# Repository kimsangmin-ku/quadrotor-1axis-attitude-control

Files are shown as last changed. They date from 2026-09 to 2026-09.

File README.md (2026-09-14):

# quadrotor-1axis-attitude-control

F450 쿼드로터의 한 축만 움직이게 지그에 고정하고, 직접 만든 제어기로 수평을 잡아보는 프로젝트.

## 왜 하죠?

이번 2학기에 듣는 [항공우주종합설계와 센서 및 계측공학] 이 두 과목에서 배우는 지식을 결합하여 실제 제어기를 만들어보고 비교적 간단한 구동 실험을 통해 실전 감각을 확보하려고

## 쓰는 것들

- 보드: STM32 Nucleo-F446RE
- IMU: MPU-6050
- 모터/ESC: 2212 1000KV × 2 (예비 1), 30A ESC × 2, 1045 프로펠러
- 지그: 알루미늄 프로파일 + 3D프린팅 (CATIA로 설계)
- 분석: Python

## 진행

- [x] 부품 발주
- [ ] 보드 세팅, 시리얼 출력
- [ ] 지그 설계 (CATIA)
- [ ] IMU 읽기
- [ ] 각도 추정 (상보필터)
- [ ] 지그 조립, 모터 구동
- [ ] PID 폐루프
- [ ] 게인 튜닝 + 데이터 정리
- [ ] 시뮬레이션이랑 비교 (시간 되면)

계획서: [docs/project_plan.md](docs/project_plan.md)
진행 기록: [docs/progress_log.md](docs/progress_log.md)

## 결과

(아직 없음)

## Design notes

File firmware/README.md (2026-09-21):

# firmware

개인 소유 **STM32 Nucleo-F446RE** 용 PlatformIO 프로젝트.
항공우주종합설계 수업의 LPC1768 프로젝트와는 폴더·플랫폼(`ststm32` vs `nxplpc`)·코드 모두 별개이며,
수업 코드를 복사하지 않고 처음부터 작성한다.

## 빌드·업로드

1. VS Code에서 **이 저장소 루트가 아니라 `firmware` 폴더**를 연다 (File → Open Folder).
2. Nucleo를 ST-LINK 쪽 USB(보드 위쪽)로 PC에 연결한다. 수업 보드는 동시에 꽂지 않는다.
3. PlatformIO 상태바의 → (Upload) 클릭. 첫 빌드는 mbed 라이브러리를 받느라 수 분 걸린다.
4. 플러그 아이콘 (Serial Monitor) 클릭. 115200 bps.

성공 기준: 초록 LED(LD2)가 0.5초마다 깜빡이고, 모니터에 `tick N  t=... ms` 가 흐른다.

## 구조 (예정)

```
firmware/
├── platformio.ini
├── src/
│   ├── main.cpp        제어 루프 (100 Hz)          ← 현재: LED + 시리얼 생존 확인
│   ├── imu.cpp/.h      MPU-6050 I2C 읽기
│   ├── filter.cpp/.h   상보필터
│   ├── pid.cpp/.h      PID 제어기
│   └── logger.cpp/.h   UART CSV 로깅
└── docs/wiring.md      배선도
```

## 진행

- [x] platformio.ini + main.cpp 생성 (2026-09-21)
- [x] 보드 업로드·시리얼 출력 확인 (2026-09-21, mbed 드라이브 복사 방식)
- [x] MPU-6050 읽기 (2026-09-21, 클론 칩 WHO_AM_I=0x72)
- [ ] 상보필터 roll 각도 추정

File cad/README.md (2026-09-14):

# cad

1축 테스트 지그 설계 파일.

- `*.CATPart`, `*.CATProduct`, `*.CATDrawing` : CATIA 원본
- `step/` : STEP 내보내기 (타 프로그램에서 열람용)
- `drawings/` : 2D 도면 PDF
- `bom.md` : 부품표
- `design_notes.md` : 재료·치수 선정 근거, 지그 강성 손계산

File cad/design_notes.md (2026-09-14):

# 프레임 재료
3개 정도 후보에 있음

1. 알루미늄 프로파일
2. 목재
3. 3d 프린팅

# 각각 특징 그리고 현실적으로 되는지...
1. 알루미늄 프로파일 : 강성 좋음, 수정 가능(**)
2. 목재 : 저렴함, 도구 필요, 수정 어려움;
3. 3d 프린팅 : 내가 의도한대로 만들 수 있음 but 큰 부품 만들면 휠 가능성 배제 못함. 

## 결정
- (9/14) 알루미늄으로 가자.
 치수 수정이 가능하다는 점을 포기할 수가 없음.

## 쓰고나서 후기 남겨볼게요
---

## 2. 회전축 방식

(볼베어링 / 부싱 / 볼트 구멍 — 위와 같은 형식으로)

## 3. 보드

(Nucleo / Arduino / ESP32)

## 4. 전원

(파워서플라이 / LiPo)

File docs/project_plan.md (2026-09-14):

# 개인프로젝트 I 계획서
## 1축 테스트벤치 기반 쿼드로터 자세 안정화 제어기 개발·검증

작성일: 2026-09-14 | 작성자: 김상민 | 기간: 2026-09-15 ~ 2026-12-04 (12주)

---

## 1. 프로젝트 한 줄 정의

F450 쿼드로터의 한 축(roll)만 회전하도록 고정하는 시소형 테스트 지그를 직접 설계·제작하고, 개인 소유 MCU로 IMU 기반 자세 추정과 PID 제어기를 구현해 수평 유지 성능을 정량적으로 시험·튜닝·검증한다.

## 2. 왜 이 주제인가 (지원 직무와의 연결)

| 결과물 층 | 산출물 | 앞세울 회사·직무 |
|---|---|---|
| 1층 설계 | CATIA 3D 모델, 2D 도면, BOM, 설계 근거서, 지그 강성 손계산 | KAI·한화에어로·LIG 기계/구조 설계, 현대차 차량시스템 설계 |
| 2층 제어 | 자세 추정 코드, PID 제어 코드, 게인별 스텝응답 표·그래프 | 현대차 차량제어 SW, LG전자 로봇, 방산 유도제어·항공전자 |
| 3층 검증 | 1축 동역학 모델(Python/MATLAB), 시뮬레이션 vs 실측 비교 | 현대차 SDV, 방산 디지털 엔지니어링·시험평가 |

프로젝트는 하나, 자소서 서사는 세 개. 회사마다 바뀌는 건 프로젝트가 아니라 강조하는 층이다.

## 3. 전제와 제약

- 보유 부품 없음 (Mbed LPC1768은 수업용 대여 보드이므로 개인 프로젝트에는 사용하지 않음)
- 예산 30~80만 원
- 작업 시간은 평일만, 주당 약 6~8시간 가정
- 실제 비행 없음 (장소·자격증 문제) → 벤치 시험으로 전 과정 대체
- 진동해석 제외, 3D프린팅은 온라인 출력 대행
- 수업(항공전자모빌리티종합설계)과의 구분: 수업은 "시중 드론 보드 교체 후 동작", 개인 프로젝트는 "제어기 한 개를 실물에서 정량 시험·튜닝·검증"

## 4. MCU 선정 (핵심 결정)

**추천: STM32 Nucleo-F446RE (또는 F401RE)** — 약 2~3만 원

- 수업에서 쓰는 Mbed 생태계와 동일해 수업에서 배운 코드·PlatformIO 환경이 그대로 이식됨 (학습 비용 최소)
- 개인 소유이므로 프로젝트 소유권이 명확하고 졸업 후에도 보유
- STM32는 현대차·LG·방산 임베디드 직무에서 실제로 가장 많이 쓰는 계열이라 이력서에 쓸 때 가장 유리
- 대안: Arduino Nano (1만 원, 가장 쉬움, 어필도는 낮음) / ESP32 (1만 원, 무선 로깅 편리, 항공·차량 쪽 어필은 STM32보다 약함)

## 5. 부품 목록 및 예산 (예상)

| 구분 | 품목 | 수량 | 예상 금액 |
|---|---|---|---|
| MCU | Nucleo-F446RE | 1 | 30,000 |
| 센서 | MPU-6050 (또는 MPU-9250) IMU 모듈 | 1 | 5,000 |
| 구동 | 2212 920KV 브러시리스 모터 | 2 (+예비 1) | 40,000 |
| 구동 | 30A ESC (BLHeli) | 2 | 25,000 |
| 구동 | 8045 프로펠러 세트 (정·역회전) | 2세트 | 10,000 |
| 기체 | F450 프레임 (팔 2개 + 센터 플레이트 사용) | 1 | 25,000 |
| 전원 | 12V 10A 이상 DC 파워서플라이 (LiPo 대신, 벤치용이라 안전) | 1 | 30,000 |
| 지그 | 2020 알루미늄 프로파일 + 브라켓 + 볼트 | 1식 | 30,000 |
| 지그 | 볼베어링 (608ZZ 등), 8mm 샤프트 | 1식 | 10,000 |
| 지그 | 3D프린팅 출력 대행 (베어링 하우징, 기체 마운트, 프로펠러 가드) | 1식 | 40,000 |
| 기타 | 점퍼선, 브레드보드, XT60/바나나 커넥터, 케이블타이, 절연테이프 | 1식 | 15,000 |
| 안전 | 보호안경, 비상정지용 토글 스위치 | 1식 | 10,000 |
| **합계** | | | **약 270,000원** (예비비 포함 35만 원 이내) |

발주 우선순위: MCU·IMU → 모터·ESC·전원 → 프레임·지그 재료 → 출력 대행(설계 완료 후).

## 6. 주차별 일정 (12주)

| 주차 | 기간 | 목표 | 완료 기준 |
|---|---|---|---|
| 1 | 9/15~9/19 | 요구사항 정의, 1축 개념설계 스케치, 1차 부품 발주 (MCU·IMU·모터·ESC·전원) | 요구사항 문서 1장, 발주 완료 |
| 2 | 9/22~9/26 | PlatformIO 환경 세팅, Nucleo LED·시리얼 동작, 1축 동역학 손계산 (추력↔토크↔각가속도) | "Hello" 시리얼 출력, 계산 노트 1장 |
| 3 | 9/29~10/3 | CATIA 지그 설계 (프로파일 프레임, 베어링 하우징, 기체 마운트, 프로펠러 가드) | 3D 모델 완성 |
| 4 | 10/6~10/10 | 도면·BOM 작성, 지그 강성 손계산(외팔보 처짐), 출력 대행·프로파일 발주 / IMU I2C 읽기 | 도면 세트, IMU 원시값 시리얼 출력 |
| 5 | 10/13~10/17 | 상보필터로 roll 각도 추정, 정지·기울임 상태에서 각도 검증 (중간고사 주간 — 부하 낮게) | 각도 ±2° 이내 추정 |
| 6 | 10/20~10/24 | 지그 조립, ESC 캘리브레이션, 모터 PWM 개루프 구동, 비상정지 확인 | 두 모터 독립 구동, 지그에서 수동 균형 확인 |
| 7 | 10/27~10/31 | P 제어만으로 폐루프 첫 동작, 시리얼 데이터 로깅 파이프라인 (CSV) | 제어 루프 100Hz 이상, 로그 파일 생성 |
| 8 | 11/3~11/7 | PID 완성, 게인 튜닝 1차 (Ziegler-Nichols 또는 수동) | 스텝 입력에서 수평 복귀 |
| 9 | 11/10~11/14 | 게인별 스텝응답 비교 실험 (최소 5세트), 오버슈트·정착시간·정상상태오차 표·그래프 | 비교표 + 그래프 완성 ← **최소 완료선** |
| 10 | 11/17~11/21 | (3층) Python으로 1축 모델 구성, 시뮬레이션 스텝응답 | 시뮬레이션 그래프 |
| 11 | 11/24~11/28 | (3층) 시뮬레이션 vs 실측 겹쳐 그리기, 오차 원인 분석 1문단 / 포트폴리오 초안 | 비교 그래프, 초안 |
| 12 | 12/1~12/4 | 최종 문서화, 동작 영상 촬영, 회사별 서사 3종 정리 | 포트폴리오 PDF, 영상 1분 |

**컷 규칙**: 11/14까지 9주차(스텝응답 비교표)가 안 끝나면 10~11주차(3층)를 버리고 2층 완성도에 집중한다. 완성된 두 층이 미완성 세 층보다 강하다.

## 7. 최종 산출물

1. 설계 패키지: CATIA 모델, 도면, BOM, 설계 근거서(재료·치수 선정 이유), 강성 손계산
2. 코드: GitHub 저장소 (README에 배선도, 빌드 방법, 제어 구조도)
3. 실험 데이터: 게인별 스텝응답 CSV + 그래프 + 비교표
4. (선택) 모델 검증: 시뮬레이션 vs 실측 비교 그래프 + 분석
5. 포트폴리오 문서 (PDF 6~10쪽) + 동작 영상 1분
6. 회사별 자소서용 서사 3종 (설계형 / 제어형 / 설계-제어 통합형)

## 8. 리스크와 대응

| 리스크 | 대응 |
|---|---|
| 부품 배송 지연 (해외 직구 시 2~3주) | 국내 재고 우선 구매, 1주차에 즉시 발주 |
| 출력 대행 치수 오차로 베어링 안 맞음 | 하우징 공차 +0.2mm, 조립 전 시험 출력 1개 |
| IMU 진동 노이즈로 각도 튐 | 센서를 폼테이프로 마운트, 필터 계수 조정, 로우패스 추가 |
| 모터 진동·프로펠러 파손 위험 | 프로펠러 가드 필수, 보호안경, 비상정지 스위치, 첫 구동은 저출력 |
| 중간고사·수업 프로젝트와 시간 충돌 | 5주차 부하 낮게 설계, 컷 규칙 적용 |
| 수업 프로젝트와 "같은 것 아니냐"는 질문 | 목표 차이(동작 vs 정량 검증)와 개인 소유 하드웨어·독자 코드로 답변 준비 |

## 9. 다음 행동 (이번 주)

- Nucleo-F446RE, MPU-6050, 2212 모터 3개, 30A ESC 2개, 12V 파워서플라이 발주
- PlatformIO에 Nucleo 프로젝트 생성, 시리얼 출력 확인
- 1축 동역학 손계산 노트 작성 (모터 추력 데이터시트 값 기준)
- GitHub 저장소 생성, 이 계획서를 README 초안으로 사용

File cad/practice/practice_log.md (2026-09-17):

# CATIA 연습 기록

지그 설계(3주차) 전에 감 잡기용으로 실제 부품을 하나씩 모델링하면서 남기는 기록.
각 항목은 날짜 · 작업 · 사용 명령 · 막힌 것 · 다음 할 것 순서로 짧게.

## 2026-09-15 베어링 하우징 (JIG-B-01)

- 파일: `bearing_housing.CATPart`
- 작업: 40×72×6 플레이트 + Ø32 보스(높이 10), 베어링 포켓 Ø22.4 깊이 7, Ø12 관통, 볼트홀 2×Ø5.5(간격 18), 코너 R5
- 사용 명령: Pad ×2, Pocket ×4, 스케치 구속
- 잘된 것: 전체 형상은 도면대로 나옴 (플레이트·보스·포켓·관통·볼트홀)
- 고칠 것
  - 구멍을 전부 Pocket으로 뚫음 → 볼트홀·Ø12 관통은 Hole 명령으로 교체 (Positioning Sketch로 위치 구속, 보스 동심은 원 모서리 + 면 Ctrl 선택)
  - Sketch.5 빈 스케치 삭제
  - 코너 R5를 스케치에서 그림 → Edge Fillet 피처로 변경
  - 포켓 입구 Chamfer C1 아직 없음
  - 피처 이름 정리 (Pad.1 → Plate, Pad.2 → Boss, Pocket.3 → BearingPocket …)
- 다음: 위 수정 후 Drafting 워크벤치에서 삼면도 + 단면 A-A 뽑기
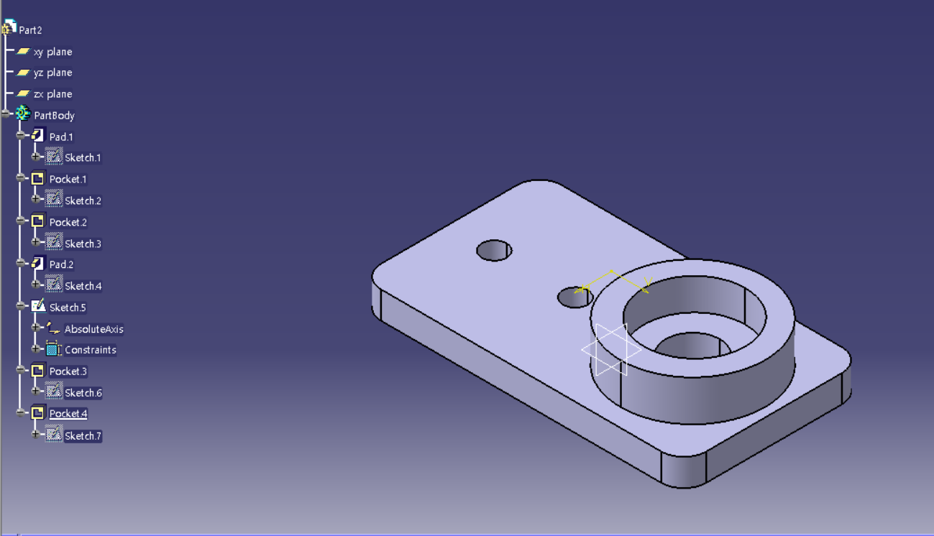
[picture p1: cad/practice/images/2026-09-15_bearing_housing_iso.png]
- 캡처: 

## 2026-09-16 센터 마운트 (JIG-C-01)

- 파일: `center_mount.CATPart`
- 작업: 플랜지 60×40×4 + 기둥 24×24×18 + 클램프 블록 24×30×24, 보어 Ø8.2 관통(높이 33), 슬릿 1.5, 클램프 볼트홀 2×Ø3.2(Y=±9, Z=41), 슬롯 4× 3.4×8
- 사용 명령: Pad ×3, Hole ×2(Positioning Sketch로 위치 구속), Pocket(슬릿·슬롯), Mirror ×3, 스케치 Corner
- 잘된 것: 3층 구조·보어·슬릿·볼트홀 도면대로 나옴. 구멍은 처음부터 Hole 명령으로 함
- 막힌 것
  - 슬롯 4개를 Mirror로 만들려다 "Mirror로 만든 피처는 다시 Mirror 불가" 에러 → 네 번째 슬롯은 Pocket.5로 따로 뚫음. 다음엔 Rectangular Pattern(44×28, 2×2)으로
  - 기둥 밑동 Edge Fillet R3: Pad할 때 겹치는 오류(Pad.2·Pad.3 겹침)로 밑동 모서리가 인식되지 않아 필렛 불가 ("Edges or face not found"). 다른 모서리는 정상 → 기둥/블록 스케치 평면 재확인 필요
- 고칠 것
  - mirror 문제를 그냥 스케치+포켓으로 해결
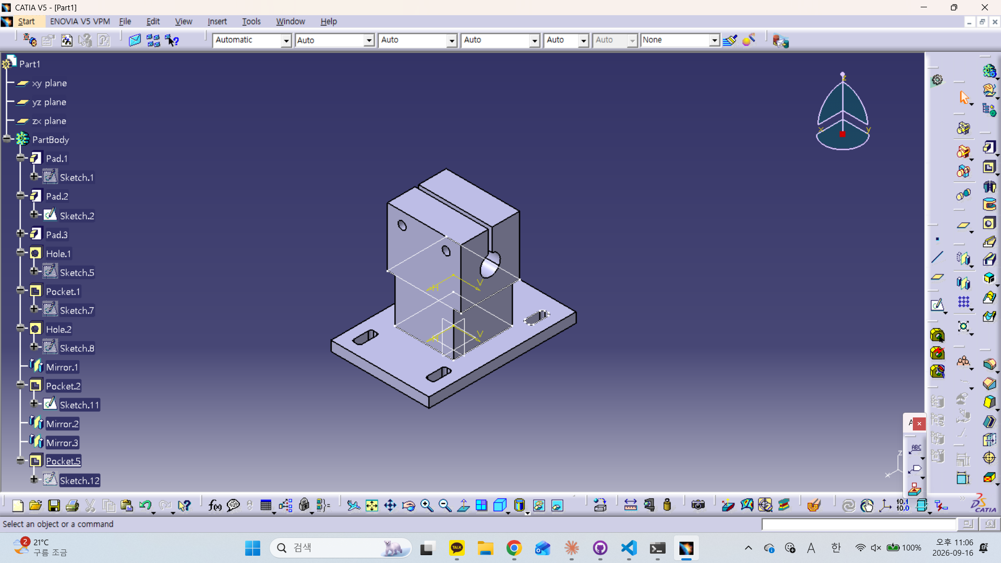
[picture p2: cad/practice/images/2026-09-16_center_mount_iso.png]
- 캡처: 

## 연습 후보 (진행 순서)

1. ~~베어링 하우징 (JIG-B-01)~~ (수정 사항 남음)
2. ~~센터 마운트 (JIG-C-01)~~ (수정 사항 남음)
3. 2020 프로파일 단면 스케치 → Pad (프레임 부재)
4. 1축 지그 Assembly Design (프로파일 + 하우징 + 샤프트 + 암), 회전 자유도 1개만 남기기
5. 브라켓 도면 1장 (치수·공차)

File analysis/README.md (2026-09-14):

# analysis

- `data/` : 대표 실험 데이터 (CSV, 게인 세트별)
- `step_response.py` : 스텝응답에서 오버슈트·정착시간·정상상태오차 계산 및 그래프
- `sim_1axis.py` : 1축 동역학 모델 시뮬레이션, 실측과 비교
- `figures/` : 생성된 그래프

실행
```
pip install numpy matplotlib pandas
python step_response.py data/kp2.0_ki0.1_kd0.5.csv
```

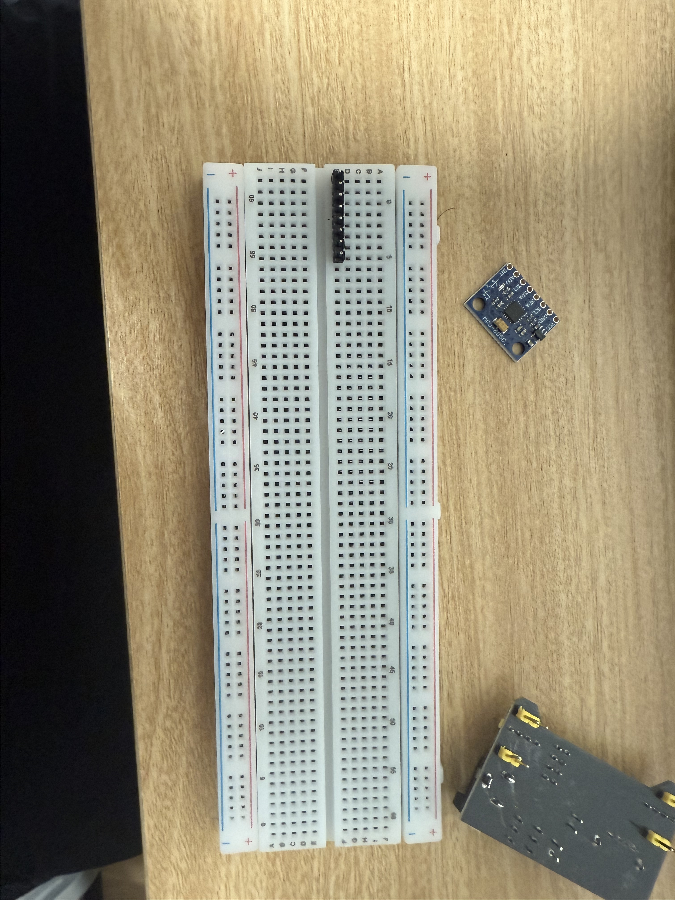
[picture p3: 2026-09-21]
firmware/docs/breadboard.png

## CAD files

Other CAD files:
cad/practice/bearing_housing.CATPart
cad/practice/center_mount.CATPart

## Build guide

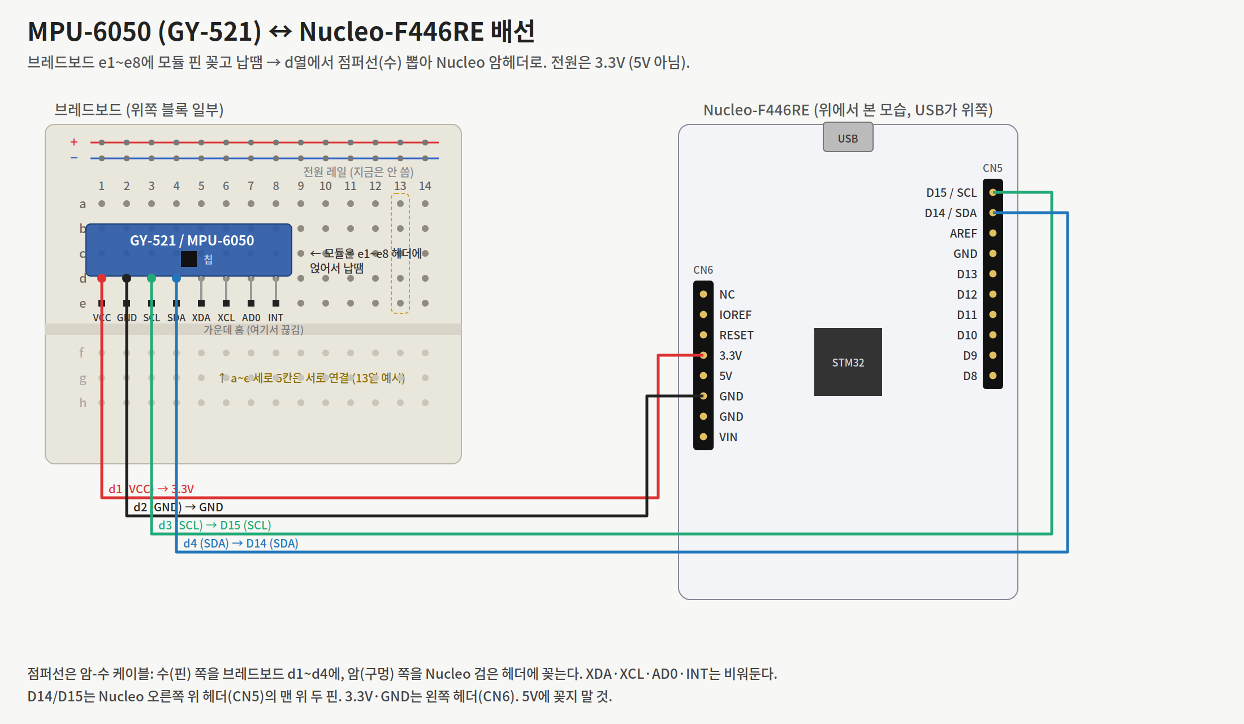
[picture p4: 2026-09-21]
firmware/docs/wiring_mpu6050.png

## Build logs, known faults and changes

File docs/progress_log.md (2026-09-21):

# 진행 기록

## 2026-09-14
- 저장소 만들고 계획 잡음
- 부품 주문
  부품명 / 수량 / 가격(일괄,KRW)
  STM32 Nucleo-F446RE / 1개 / 36000
  BLDC 브러시리스 모터 2212 1000KV + 30A ESC + 1045 프로펠러 세트 [TYE-DR059] / 3개 / 54000
  MPU-6050 IMU / 2개 / 9000
  터미널블럭 to DC 커넥터 (DC2.1 FEMALE) [SZH-LC002] / 2개 / 1000
  아답터, 220v / 12V 10A 젠더 세트 4종 젠더 HT-AD011 / 1개 / 36300
  830핀 브레드보드 전원 공급 키트 [MD0187] / 1개 / 4400
  방수캡 토글 스위치 ON-OFF 2단스위치 15A 12mm [T-TS15A2P] / 1개 / 2700
  보안경 / 1개 / 2800
  테스트[CH254] 소켓 점퍼 케이블 40P (칼라) (M/F) 20cm / 1개 / 850
  NT- DIY 수축튜브 328세트 / 1개 / 3900
  전기 인두기 세트 / 1개 / 17500
  ----------------------------------------------------------------------------------------
  합계 : 부가세 포함 183545 (KRW)

- 1축 관성모멘트 계산해보기
  I = 2×0.07×0.22² + (1/12)×0.06×0.44² = 0.007744 kg·m²
  왼쪽 모터가 1N 더 밀면 τ = 0.22 N·m, α = 28.4 rad/s² = 1627.84 °/s²
  → 0.2초면 30도 넘게 기움. 100Hz 루프, 게인 작게, 지그에 각도 스토퍼 필요
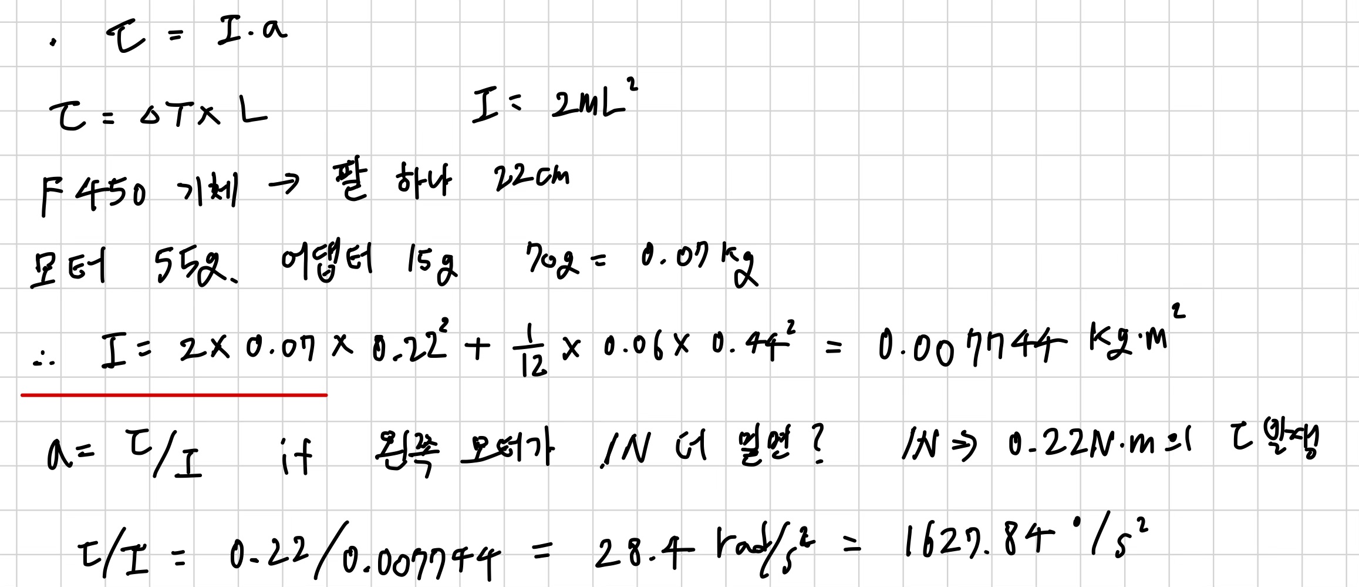
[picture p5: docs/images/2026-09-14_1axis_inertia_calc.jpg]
관성 손계산
  

## 2026-09-15
- CATIA bearinghouse 제작 연습

## 2026-09-16
- CATIA center mount 제작 연습

## 2026-09-21
- 1차 주문 부품 전부 도착, 검수 완료
- 실제 온 모터/프로펠러가 1000KV·1045 세트라 계획서의 920KV·8045 기준 손계산은 이 값으로 다시 할 것
- firmware/ 에 PlatformIO 프로젝트 생성 (nucleo_f446re, mbed)
- 다음: Nucleo 업로드해서 LED·시리얼 확인 → MPU-6050 납땜 후 I2C 읽기
- IMU 납땜·배선·읽기 성공. 

- 약 4시간 동안 뭘 했는지?
  1. `OpenOCD init failed` → ST-LINK 드라이버 없음. platformio.ini `upload_protocol = mbed`로 우회 (NOD_F446RE 드라이브에 .bin 복사)
  2. 납땜 실력이 좋지 않아서 인두 팁이 자꾸 산화가 됨. 그래서 팁에서 납이 녹지 않아 납땜하기가 많이 빡셌음.
  3. 배선 문제는 없었던 것 같은데 핀과 패드 연결이 원활하지 않음.
  
- 오늘을 기점으로 당분간 해야할 것.
  1. 납땜 연습하기. 아직 납땜에 용이한 용품들이 오지 않아서 배송 오고 나서 본격적으로 연습.
  2. 앞으로 무엇을 해야할 지 한번 체크해보고 전체적으로 구상 다시 해보기.

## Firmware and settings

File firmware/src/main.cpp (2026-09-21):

// firmware/src/main.cpp
// 2단계: MPU-6050 I2C 읽기 - WHO_AM_I 확인 후 가속도·자이로 원시값을 10 Hz로 출력
//
// 배선 (Nucleo-F446RE Arduino 헤더 기준)
//   MPU-6050 VCC → 3.3V
//   MPU-6050 GND → GND
//   MPU-6050 SDA → D14 (PB_9)
//   MPU-6050 SCL → D15 (PB_8)
//   (AD0, INT, XDA, XCL은 비워둠)

#include "mbed.h"
#include "imu.h"

static DigitalOut led(LED1);
static BufferedSerial pc(USBTX, USBRX, 115200);
static Mpu6050 imu(I2C_SDA, I2C_SCL);   // = D14, D15

static void print(const char *s) { pc.write(s, strlen(s)); }

int main()
{
    char line[128];
    print("\r\n[quadrotor-1axis] stage 2: MPU-6050 raw read\r\n");

    // I2C 버스 스캔: 응답하는 주소를 전부 출력 (배선 진단용)
    {
        I2C bus(I2C_SDA, I2C_SCL);
        bus.frequency(100000);
        print("I2C scan: ");
        int found = 0;
        for (int a = 0x08; a < 0x78; a++) {
            char dummy = 0;
            if (bus.read(a << 1, &dummy, 1) == 0) {
                snprintf(line, sizeof(line), "0x%02X ", a);
                print(line);
                found++;
            }
        }
        if (found == 0) print("(none - check VCC/GND/SDA/SCL)");
        print("\r\n");
    }

    bool ok = imu.init();
    snprintf(line, sizeof(line), "WHO_AM_I = 0x%02X (%s)  init=%s (err %d)\r\n",
             imu.whoAmI(), imu.whoAmI() == 0x68 ? "MPU-6050" : "MPU-6050 clone",
             ok ? "OK" : "FAIL", imu.lastErr());
    print(line);

    Timer t;
    t.start();

    while (true) {
        led = !led;

        if (ok) {
            ImuRaw r;
            if (imu.read(r)) {
                // mbed 기본 printf는 %f 미지원 → 정수로 출력 (mg, 0.1 dps, 0.1 C)
                int ax = (int)(r.ax * 1000L / (long)Mpu6050::ACC_LSB_G);
                int ay = (int)(r.ay * 1000L / (long)Mpu6050::ACC_LSB_G);
                int az = (int)(r.az * 1000L / (long)Mpu6050::ACC_LSB_G);
                int gx = (int)(r.gx * 100L / Mpu6050::GYRO_LSB_DPS10);   // 0.1 dps 단위
                int gy = (int)(r.gy * 100L / Mpu6050::GYRO_LSB_DPS10);
                int gz = (int)(r.gz * 100L / Mpu6050::GYRO_LSB_DPS10);
                int tc = (int)(r.temp * 10L / 340 + 365);
                snprintf(line, sizeof(line),
                         "t=%6lld ms  acc[mg] %+5d %+5d %+5d  gyro[0.1dps] %+5d %+5d %+5d  T=%d.%dC\r\n",
                         (long long)t.elapsed_time().count() / 1000,
                         ax, ay, az, gx, gy, gz, tc / 10, tc % 10);
            } else {
                snprintf(line, sizeof(line), "read fail\r\n");
            }
        } else {
            ok = imu.init();
            snprintf(line, sizeof(line), "IMU init retry: %s (err %d)\r\n",
                     ok ? "OK" : "FAIL", imu.lastErr());
        }
        print(line);

        ThisThread::sleep_for(100ms);   // 10 Hz 출력 (확인용)
    }
}

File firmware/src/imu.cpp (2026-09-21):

#include "imu.h"

namespace {
    constexpr uint8_t REG_SMPLRT_DIV   = 0x19;
    constexpr uint8_t REG_CONFIG       = 0x1A;
    constexpr uint8_t REG_GYRO_CONFIG  = 0x1B;
    constexpr uint8_t REG_ACCEL_CONFIG = 0x1C;
    constexpr uint8_t REG_ACCEL_XOUT_H = 0x3B;
    constexpr uint8_t REG_PWR_MGMT_1   = 0x6B;
    constexpr uint8_t REG_WHO_AM_I     = 0x75;
}

Mpu6050::Mpu6050(PinName sda, PinName scl) : _i2c(sda, scl)
{
    _i2c.frequency(100000);   // 100 kHz (점퍼선 배선에서 안정적)
}

bool Mpu6050::writeReg(uint8_t reg, uint8_t val)
{
    char buf[2] = { (char)reg, (char)val };
    return _i2c.write(ADDR_8BIT, buf, 2) == 0;
}

bool Mpu6050::readRegs(uint8_t reg, uint8_t *buf, int len)
{
    char r = (char)reg;
    if (_i2c.write(ADDR_8BIT, &r, 1, true) != 0) return false;   // repeated start
    return _i2c.read(ADDR_8BIT, (char *)buf, len) == 0;
}

uint8_t Mpu6050::whoAmI()
{
    uint8_t v = 0;
    readRegs(REG_WHO_AM_I, &v, 1);
    return v;
}

bool Mpu6050::init()
{
    // 1) 먼저 살아있는지 확인
    //    정품 MPU-6050은 0x68. 시중 GY-521 클론 칩은 0x70/0x72/0x98 등을 돌려주지만
    //    레지스터 맵이 같아 동일하게 동작하므로 "응답이 있으면" 통과시킨다.
    uint8_t id = whoAmI();
    if (id == 0x00 || id == 0xFF) { _lastErr = 1; return false; }
    _whoAmI = id;

    // 2) 슬립 해제 (리셋은 생략 - 전원 인가 시 기본값이면 충분)
    if (!writeReg(REG_PWR_MGMT_1, 0x01)) { _lastErr = 2; return false; }   // 클럭 = X 자이로 PLL
    ThisThread::sleep_for(10ms);

    // 3) 설정 (하나라도 실패하면 단계 번호 기록)
    if (!writeReg(REG_SMPLRT_DIV, 0x04))   { _lastErr = 3; return false; }  // 200 Hz
    if (!writeReg(REG_CONFIG, 0x03))       { _lastErr = 4; return false; }  // DLPF 44 Hz
    if (!writeReg(REG_GYRO_CONFIG, 0x08))  { _lastErr = 5; return false; }  // ±500 dps
    if (!writeReg(REG_ACCEL_CONFIG, 0x08)) { _lastErr = 6; return false; }  // ±4 g

    // 4) 설정이 실제로 들어갔는지 읽어서 확인
    uint8_t v = 0;
    if (!readRegs(REG_PWR_MGMT_1, &v, 1) || (v & 0x40)) { _lastErr = 7; return false; } // 아직 슬립?
    _lastErr = 0;
    return true;
}

bool Mpu6050::read(ImuRaw &o)
{
    uint8_t b[14];
    if (!readRegs(REG_ACCEL_XOUT_H, b, 14)) return false;
    o.ax   = (int16_t)((b[0] << 8) | b[1]);
    o.ay   = (int16_t)((b[2] << 8) | b[3]);
    o.az   = (int16_t)((b[4] << 8) | b[5]);
    o.temp = (int16_t)((b[6] << 8) | b[7]);
    o.gx   = (int16_t)((b[8] << 8) | b[9]);
    o.gy   = (int16_t)((b[10] << 8) | b[11]);
    o.gz   = (int16_t)((b[12] << 8) | b[13]);
    return true;
}

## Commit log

2026-09-14 프로젝트 구조 및 README
2026-09-14 관성 계산 추가
2026-09-14 Add practice log for CATIA modeling exercises
    - Created a new markdown file to document the progress of CATIA modeling exercises.
    - Included details for the first exercise: Bearing Housing (JIG-B-01) with specifications, commands used, and future tasks.
    - Established a list of upcoming practice candidates to guide future work.
    [bearing_housing.CATPart]
2026-09-21 firmware: Nucleo-F446RE PlatformIO 프로젝트 생성, LED+시리얼 동작 확인
2026-09-21 2026-09-21_기록
2026-09-22 이미지 추가
